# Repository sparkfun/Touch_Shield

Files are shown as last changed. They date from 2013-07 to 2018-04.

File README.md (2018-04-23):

**NOTE:** *This product has been retired from our catalog. If you are looking for more up-to-date info, please check out some of these resources to see how other users are still hacking and improving on this product.*
* *[SparkFun Forum](https://forum.sparkfun.com/)*
* *[Comments Here on GitHub](https://github.com/sparkfun/Touch_Shield/issues)*
* *[IRC Channel](https://www.sparkfun.com/news/263)*

Touch Shield
============

[Touch Shield  
*Touch Shield (DEV-12013)*](https://www.sparkfun.com/products/12013)

The Touch Shield allows you to easily interface the MPR121 IC to your Arduino. It has 9 capacitive touch pads,
with headers for the remaining 3 electrode connections. 

Repository Contents
-------------------
* **/Firmware** - Example firmware for interfacing with the Touch Shield
* **/Hardware** - All Eagle board design files (.brd, .sch)
* **/Production** - Test bed files and production panel files

Product Versions
----------------
* [DEV-10508](https://www.sparkfun.com/products/10508)- Basic Touch Shield
* [RTL-10774](https://www.sparkfun.com/products/10774)- Retail packaging of the Touch Shield and Arduino stackable headers

Version History
---------------
* [DEV-10508](https://www.sparkfun.com/products/10508) Version 1.1

License Information
-------------------
The hardware is released under [Creative Commons Share-alike 3.0](http://creativecommons.org/licenses/by-sa/3.0/).  
All other code is open source so please feel free to do anything you want with it; you buy me a beer if you use this and we meet someday ([Beerware license](http://en.wikipedia.org/wiki/Beerware)).

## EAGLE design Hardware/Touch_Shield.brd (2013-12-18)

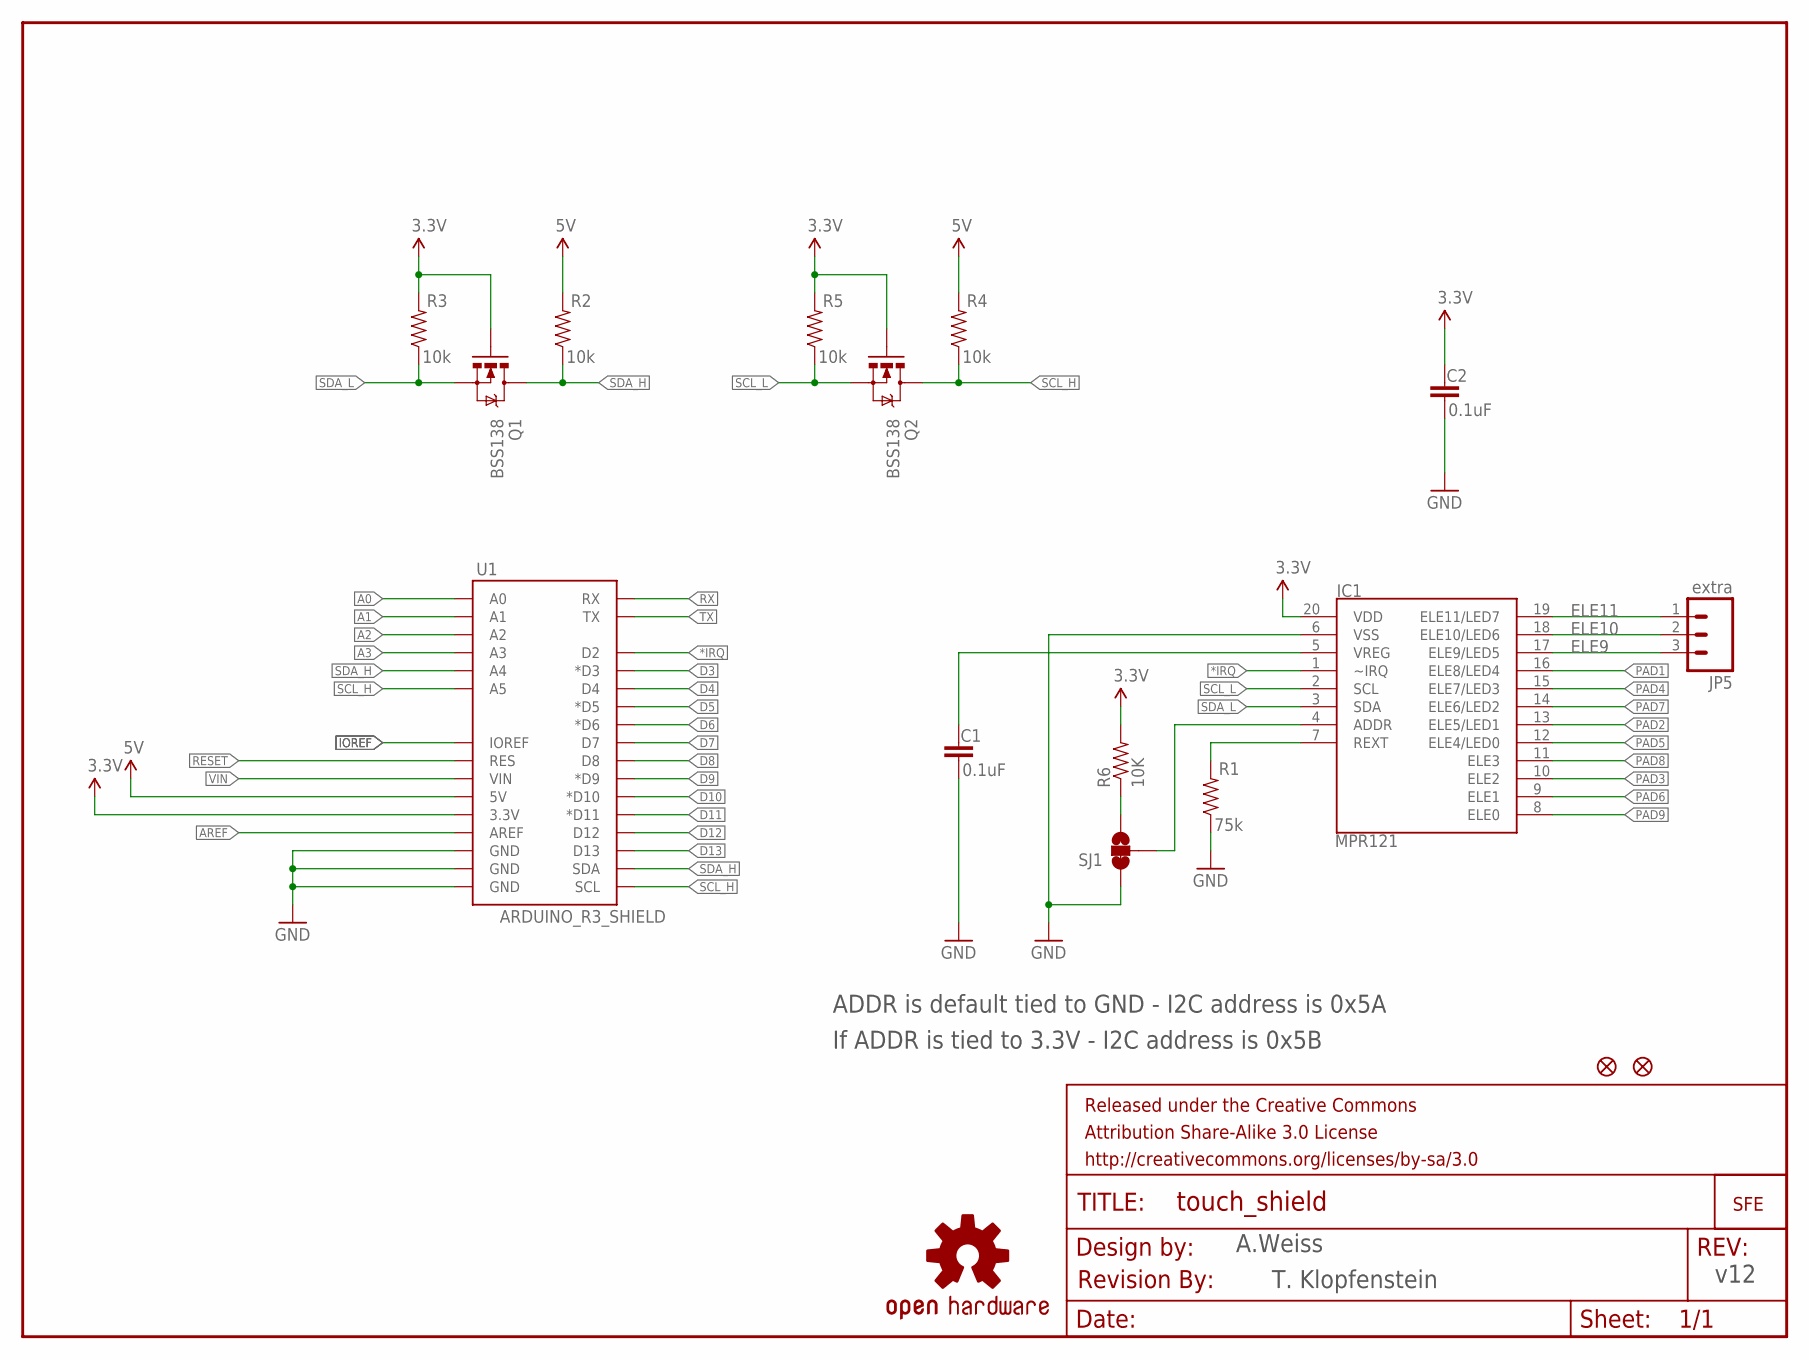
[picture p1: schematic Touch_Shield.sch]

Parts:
C1, C2: 0.1uF; 0603-CAP
FID1, FID2: FIDUCIALUFIDUCIAL; MICRO-FIDUCIAL
FRAME1: FRAME-LETTER; CREATIVE_COMMONS
IC1: MPR121; QFN-20-0.4MM-V2
JP1: LOGO-SFENEW; SFE-NEW-WEBLOGO
JP5: extra; 1X03
Q1, Q2: BSS138; SOT23-3
R1: 75k; 0603-RES
R2, R3, R4, R5: 10k; 0603-RES
R6: 10K; 0603-RES
SJ1: SOLDERJUMPER_2WAYPASTE1&2; SJ_3_PASTE1&2
U1: ARDUINO_R3_SHIELD; UNO_R3_SHIELD
U$1: REVISION
U$5: OSHW-LOGOL; OSHW-LOGO-L

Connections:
3.3V: C2.1, IC1.20 (VDD), Q1.1 (G), Q2.1 (G), R3.2, R5.2, R6.2, U1.3.3V
5V: R2.2, R4.2, U1.5V
*IRQ: IC1.1 (~IRQ), U1.D2
A0: U1.A0
A1: U1.A1
A2: U1.A2
A3: U1.A3
AREF: U1.AREF
D3: U1.D3 (*D3)
D4: U1.D4
D5: U1.D5 (*D5)
D6: U1.D6 (*D6)
D7: U1.D7
D8: U1.D8
D9: U1.D9 (*D9)
D10: U1.D10 (*D10)
D11: U1.D11 (*D11)
D12: U1.D12
D13: U1.D13
ELE9: IC1.17 (ELE9/LED5), JP5.3
ELE10: IC1.18 (ELE10/LED6), JP5.2
ELE11: IC1.19 (ELE11/LED7), JP5.1
GND: C1.2, C2.2, IC1.6 (VSS), R1.1, SJ1.1, U1.GND@0 (GND), U1.GND@1 (GND), U1.GND@2 (GND)
IOREF: U1.IOREF
unnamed: IC1.4 (ADDR), SJ1.2
unnamed: R6.1, SJ1.3
PAD1: IC1.16 (ELE8/LED4)
PAD2: IC1.13 (ELE5/LED1)
PAD3: IC1.10 (ELE2)
PAD4: IC1.15 (ELE7/LED3)
PAD5: IC1.12 (ELE4/LED0)
PAD6: IC1.9 (ELE1)
PAD7: IC1.14 (ELE6/LED2)
PAD8: IC1.11 (ELE3)
PAD9: IC1.8 (ELE0)
RESET: U1.RES
REXT: IC1.7 (REXT), R1.2
RX: U1.RX
SCL_H: Q2.3 (D), R4.1, U1.A5, U1.SCL
SCL_L: IC1.2 (SCL), Q2.2 (S), R5.1
SDA_H: Q1.3 (D), R2.1, U1.A4, U1.SDA
SDA_L: IC1.3 (SDA), Q1.2 (S), R3.1
TX: U1.TX
VIN: U1.VIN
VREG: C1.1, IC1.5 (VREG)

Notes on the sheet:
A.Weiss
ADDR is default tied to GND - I2C address is 0x5A
v12
T. Klopfenstein
If ADDR is tied to 3.3V - I2C address is 0x5B

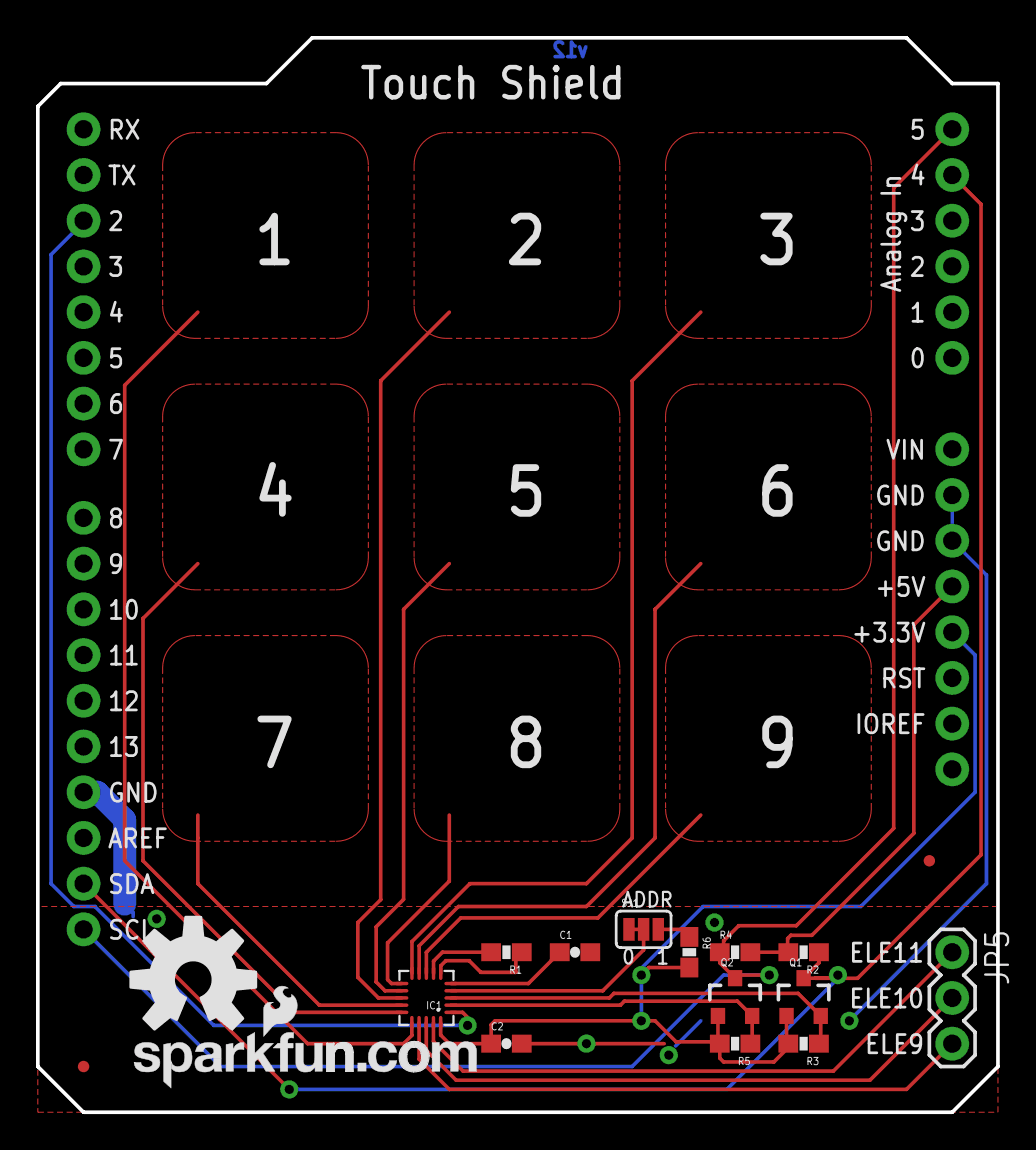
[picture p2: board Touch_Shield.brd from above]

Board: 2 copper layers, 53.3 x 59.7 mm, 20 parts (0 on the bottom side), 15 nets.

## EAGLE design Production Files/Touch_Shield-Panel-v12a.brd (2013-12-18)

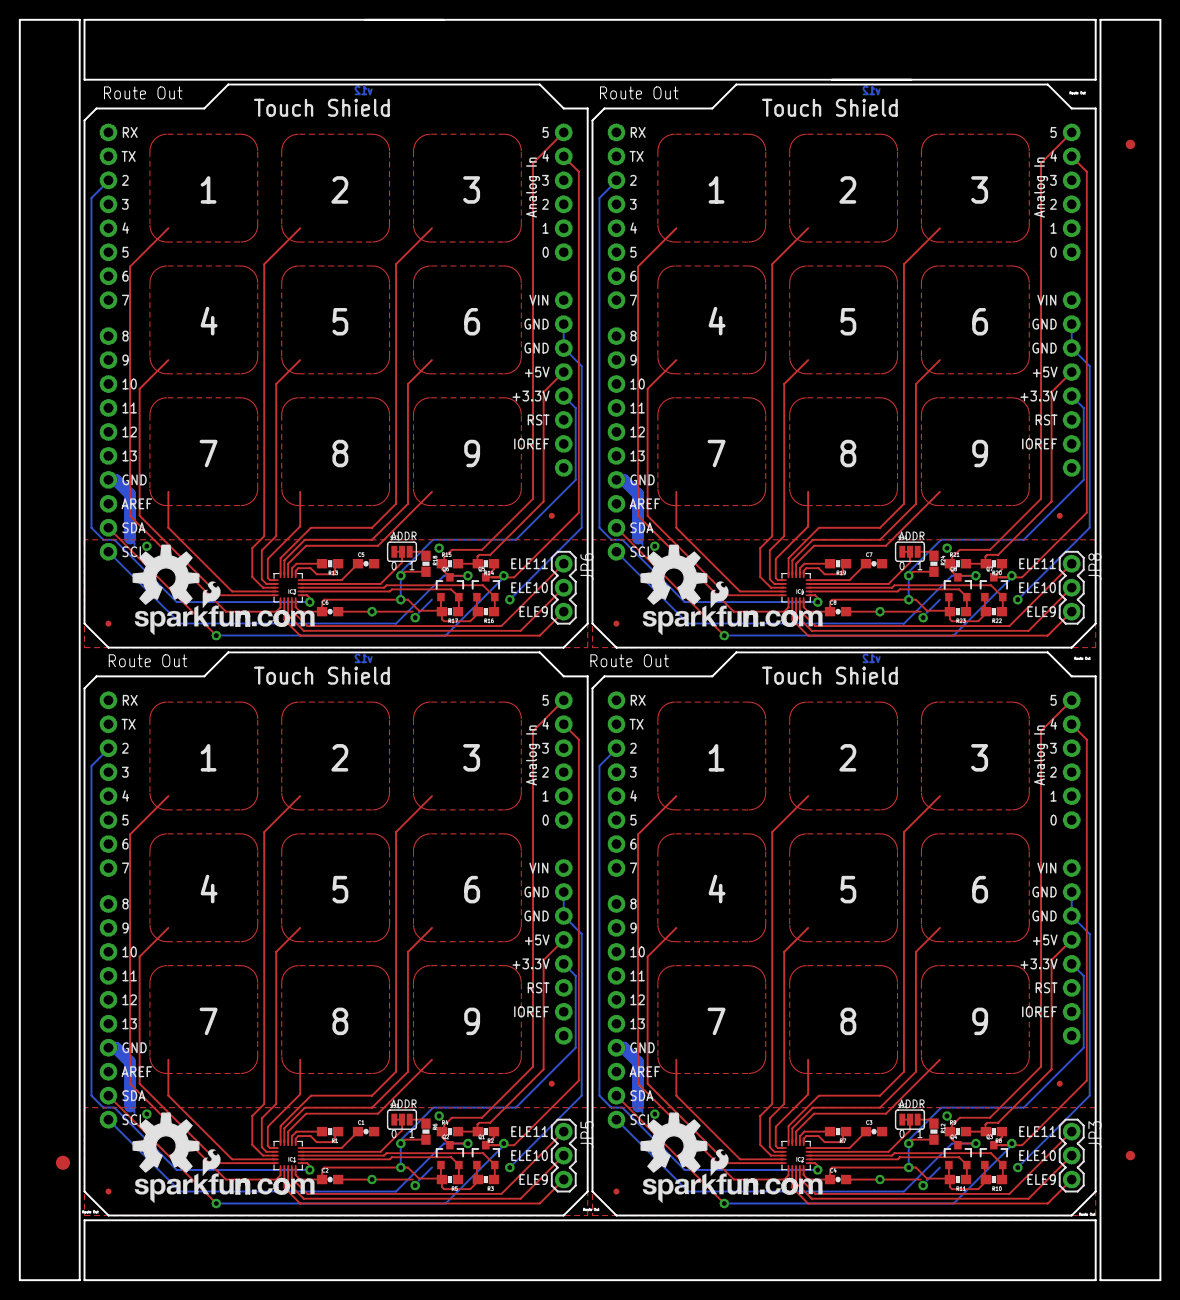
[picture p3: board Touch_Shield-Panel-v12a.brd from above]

Board: 2 copper layers, 120.9 x 133.6 mm, 75 parts (0 on the bottom side), 60 nets.

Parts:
C1, C2, C3, C4, C5, C6, C7, C8: 0.1uF; 0603-CAP
E$1: FIDUCIAL-1.5X3
E$4, E$8: FIDUCIAL-1X2
FID1, FID2, FID3, FID4, FID5, FID6, FID7, FID8: FIDUCIALUFIDUCIAL; MICRO-FIDUCIAL
IC1, IC2, IC3, IC4: MPR121; QFN-20-0.4MM-V2
JP1, JP2, JP4, JP7: LOGO-SFENEW; SFE-NEW-WEBLOGO
JP3, JP5, JP6, JP8: extra; 1X03
Q1, Q2, Q3, Q4, Q5, Q6, Q7, Q8: BSS138; SOT23-3
R1, R7, R13, R19: 75k; 0603-RES
R2, R3, R4, R5, R8, R9, R10, R11, R14, R15, R16, R17, R20, R21, R22, R23: 10k; 0603-RES
R6, R12, R18, R24: 10K; 0603-RES
SJ1, SJ2, SJ3, SJ4: SJ_3_PASTE1&2
U1, U2, U3, U4: ARDUINO_R3_SHIELD; UNO_R3_SHIELD
U$1, U$2, U$3, U$5: OSHW-LOGOL; OSHW-LOGO-L

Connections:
3.3V: C2.1, IC1.20, Q1.1, Q2.1, R3.2, R5.2, R6.2, U1.3.3V
3.3V1: C4.1, IC2.20, Q3.1, Q4.1, R10.2, R11.2, R12.2, U2.3.3V
3.3V2: C6.1, IC3.20, Q5.1, Q6.1, R16.2, R17.2, R18.2, U3.3.3V
3.3V3: C8.1, IC4.20, Q7.1, Q8.1, R22.2, R23.2, R24.2, U4.3.3V
5V: R2.2, R4.2, U1.5V
5V1: R8.2, R9.2, U2.5V
5V2: R14.2, R15.2, U3.5V
5V3: R20.2, R21.2, U4.5V
*IRQ: IC1.1, U1.D2
*IRQ1: IC2.1, U2.D2
*IRQ2: IC3.1, U3.D2
*IRQ3: IC4.1, U4.D2
ELE1: IC2.19, JP3.1
ELE2: IC2.18, JP3.2
ELE3: IC2.17, JP3.3
ELE4: IC3.19, JP6.1
ELE5: IC3.18, JP6.2
ELE6: IC3.17, JP6.3
ELE7: IC4.19, JP8.1
ELE8: IC4.18, JP8.2
ELE9: IC1.17, JP5.3
ELE10: IC1.18, JP5.2
ELE11: IC1.19, JP5.1
ELE12: IC4.17, JP8.3
GND: C1.2, C2.2, IC1.6, R1.1, SJ1.1, U1.GND@0, U1.GND@1, U1.GND@2
GND1: C3.2, C4.2, IC2.6, R7.1, SJ2.1, U2.GND@0, U2.GND@1, U2.GND@2
GND2: C5.2, C6.2, IC3.6, R13.1, SJ3.1, U3.GND@0, U3.GND@1, U3.GND@2
GND3: C7.2, C8.2, IC4.6, R19.1, SJ4.1, U4.GND@0, U4.GND@1, U4.GND@2
unnamed: IC1.4, SJ1.2
unnamed: R6.1, SJ1.3
unnamed: IC2.4, SJ2.2
unnamed: R12.1, SJ2.3
unnamed: IC3.4, SJ3.2
unnamed: R18.1, SJ3.3
unnamed: IC4.4, SJ4.2
unnamed: R24.1, SJ4.3
REXT: IC1.7, R1.2
REXT1: IC2.7, R7.2
REXT2: IC3.7, R13.2
REXT3: IC4.7, R19.2
SCL_H: Q2.3, R4.1, U1.A5, U1.SCL
SCL_H1: Q4.3, R9.1, U2.A5, U2.SCL
SCL_H2: Q6.3, R15.1, U3.A5, U3.SCL
SCL_H3: Q8.3, R21.1, U4.A5, U4.SCL
SCL_L: IC1.2, Q2.2, R5.1
SCL_L1: IC2.2, Q4.2, R11.1
SCL_L2: IC3.2, Q6.2, R17.1
SCL_L3: IC4.2, Q8.2, R23.1
SDA_H: Q1.3, R2.1, U1.A4, U1.SDA
SDA_H1: Q3.3, R8.1, U2.A4, U2.SDA
SDA_H2: Q5.3, R14.1, U3.A4, U3.SDA
SDA_H3: Q7.3, R20.1, U4.A4, U4.SDA
SDA_L: IC1.3, Q1.2, R3.1
SDA_L1: IC2.3, Q3.2, R10.1
SDA_L2: IC3.3, Q5.2, R16.1
SDA_L3: IC4.3, Q7.2, R22.1
VREG: C1.1, IC1.5
VREG1: C3.1, IC2.5
VREG2: C5.1, IC3.5
VREG3: C7.1, IC4.5

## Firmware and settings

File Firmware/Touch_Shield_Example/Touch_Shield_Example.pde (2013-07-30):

/* 
 Touch Shield Example using the MPR121 touch sensor IC 

 by: Aaron Weiss, based on the MPR121 Keypad Example by Jim Lindblom
     
 SparkFun Electronics
 created on: 5/12/11
 license: OSHW 1.0, http://freedomdefined.org/OSHW
 
 Pressing a pad will print the corresponding number.
 
 Hardware: 3.3V or 5V Arduino

 Notes: The Wiring library is not used for I2C, a default atmel I2C lib
        is used. Be sure to keep the .h files with the project. 
*/

// include the atmel I2C libs
#include "mpr121.h"
#include "i2c.h"

// 11 max digits used
#define DIGITS 11 

// Match key inputs with electrode numbers
#define ONE 8
#define TWO 5
#define THREE 2
#define FOUR 7
#define FIVE 4
#define SIX 1
#define SEVEN 6
#define EIGHT 3
#define NINE 0

//extras (not used)
#define ELE9 9
#define ELE10 10
#define ELE11 11

//interupt pin
int irqpin = 2;  // D2

void setup()
{
  //make sure the interrupt pin is an input and pulled high
  pinMode(irqpin, INPUT);
  digitalWrite(irqpin, HIGH);
  
  //configure serial out
  Serial.begin(9600);
  
  //output on ADC4 (PC4, SDA)
  DDRC |= 0b00010011;
  // Pull-ups on I2C Bus
  PORTC = 0b00110000; 
  // initalize I2C bus. Wiring lib not used. 
  i2cInit();
  
  delay(100);
  // initialize mpr121
  mpr121QuickConfig();
  
  // Create and interrupt to trigger when a button
  // is hit, the IRQ pin goes low, and the function getNumber is run. 
  attachInterrupt(0,getNumber,LOW);
  
  // prints 'Ready...' when you can start hitting numbers
  Serial.println("Ready...");
}

void loop()
{
  //You can put additional code here. The interrupt will run in the backgound. 
}

void getNumber()
{
  int i = 0;
  int touchNumber = 0;
  uint16_t touchstatus;
  char digits[DIGITS];
  
  touchstatus = mpr121Read(0x01) << 8;
  touchstatus |= mpr121Read(0x00);
  
  for (int j=0; j<12; j++)  // Check how many electrodes were pressed
  {
    if ((touchstatus & (1<<j)))
      touchNumber++;
  }
  
  if (touchNumber == 1)
  {
    if (touchstatus & (1<<SEVEN))
      digits[i] = '7';
    else if (touchstatus & (1<<FOUR))
      digits[i] = '4';
    else if (touchstatus & (1<<ONE))
      digits[i] = '1';
    else if (touchstatus & (1<<EIGHT))
      digits[i] = '8';
    else if (touchstatus & (1<<FIVE))
      digits[i] = '5';
    else if (touchstatus & (1<<TWO))
      digits[i] = '2';
    else if (touchstatus & (1<<NINE))
      digits[i] = '9';
    else if (touchstatus & (1<<SIX))
      digits[i] = '6';
    else if (touchstatus & (1<<THREE))
      digits[i] = '3';
      
    Serial.print(digits[i]);
    i++;
  }
  //do nothing if more than one button is pressed
  else if (touchNumber == 0)
    ;
  else
    ;
}

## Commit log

2013-07-30 Update board files, adding README and Firmware to repo
    [Touch_Shield.brd, Touch_Shield.sch]
2013-07-30 Adding schematic note about selectable I2C address
    [Touch_Shield.sch]
2013-08-07 Updating shield layout to R3
    [Touch_Shield.brd, Touch_Shield.sch]
2013-08-07 Updating all the resistors to the same production ID number
    [Touch_Shield.brd, Touch_Shield.sch]
2013-10-01 Created Panel
    [Touch_Shield-Panel-v12.brd]
2013-12-18 Re-panelized and added fiducials to board
    I re-did the panel to 4 boards and added local fiducials
    [Touch_Shield-Panel-v12.brd, Touch_Shield-Panel-v12a.brd, Touch_Shield.brd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]

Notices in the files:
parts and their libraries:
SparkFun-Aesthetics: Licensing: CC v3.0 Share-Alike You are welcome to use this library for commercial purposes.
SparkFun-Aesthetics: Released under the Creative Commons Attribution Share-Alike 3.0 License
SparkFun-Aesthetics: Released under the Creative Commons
